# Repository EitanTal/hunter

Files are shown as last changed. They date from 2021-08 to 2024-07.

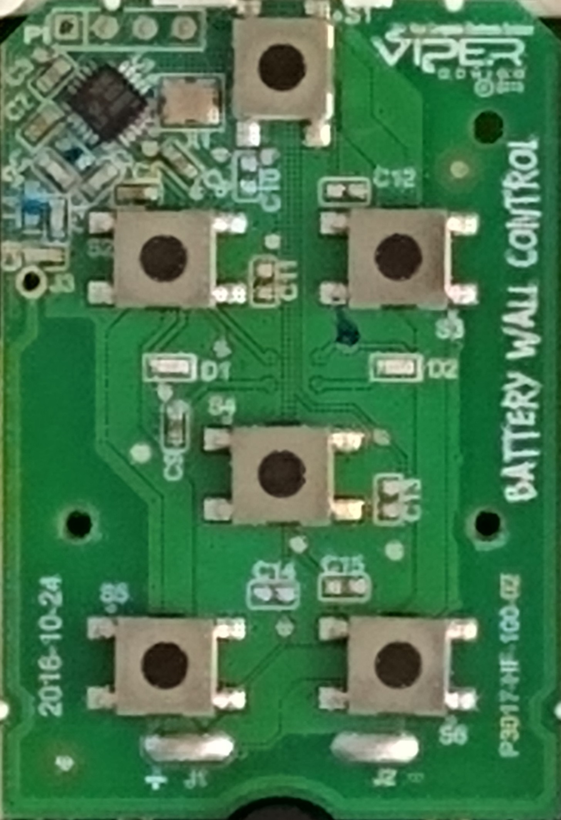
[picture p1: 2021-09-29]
PCB/ffs.jpg

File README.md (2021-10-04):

# Intro

This is a recreation of an Old-school Hunter fan remote

## Digital signals

Every packet is as follows:

   [`address`][`opcode`]

address is 5 bits long, opcode is 8 bits long. Address used = 0b01111

### Packets & Opcodes

* light:    0x0F (01111) 0x1 (00000001)
* fan off:  0x0F (01111) 0x2 (00000010)
* fan rev:                   (00000100)
* fan 3:                     (00001000)
* fan 2:                     (00010000)
* fan 1:    0x0F             (00100000)

## Pulse layout

short pulse: (0)

      _
    __

long pulse: (1)

     __
    _

## Pulse timing

length of each character: 328.4us (0.3284ms)

every 1 bit = 8us.
41 bits = one unit.
~16 bytes per triplet.

This equals a baudrate of 3045

The bit burst must repeat 16 times.
There must be exactly 10ms gap between each bit burst.

## Radio notes

### Carrier

The chosen carrier is 302MHz. The original remote is inconsistent on its carrier wave, ranging from 300 to 305.

### Modulation

On-off-keying modulation is used. (AM)

### RF backend

This implementation utilizes TI CC1101 as the RF backend. The original hunter remote presumably used a ferrite core antenna. More details are available in eariler revisions.

As an antenna, a 30cm wire is used.

For power, 0db is currently used

## Breadboard notes

CC1101 operates on 3v3 max. Resistor divider used on Arduino -> CC1101

Relevant pins on the pinheader of the eval board of CC1101:
| Color | Pin |  | Pin  | Color |
|---|---|--|---|---|
|  Brown  | VCC |  | VCC | Red |
|  Orange | SCK |  | MOSI | Yellow  |
|  Green  | GDO2  |  | MISO | Blue |
|  Purple | GDO0  |  | CSN | Grey |
|  White  | GND |  | GND | Black |

The pins as they connect to my breadboard:
| Color | Pin |  | Pin  | Color |
|---|---|--|---|---|
| (Black) |GND |  | VCC | (Red) |
| (Blue)  |MISO |  | MOSI |(Yellow) |
| (Orange)|SCK |  | CSN |  (Grey) |
| | |  | GDO0 |(Purple) |

Relevant pins on the arduino:
|Number|Function|Comment |
|---|---|---|
|10 | SS | (Active low) |
|11 | MOSI | |
|12 | MISO | |
|13 | SCLK | |
|2 | GDO0 | (Interrupt line 0, PD2) |

Breadboard jumper cables:
arduino-breadboard line
2-21
7-19
10-15
11-13
12-17
13-9

## STM8 pins

|Arduino|Function|207K (Eval board) |101F (Target)  |
|---|---|---|---|
|10 | SS |PE5 (D10) |PB4 |
|11 | MOSI |PC6 (D11) |PB6 |
|12 | MISO |PC7 (D12) |PB7 |
|13 | SCLK |PC5 (D13) |PB5 |
|2 | GDO0 |PD0 (D2) |PC0 |

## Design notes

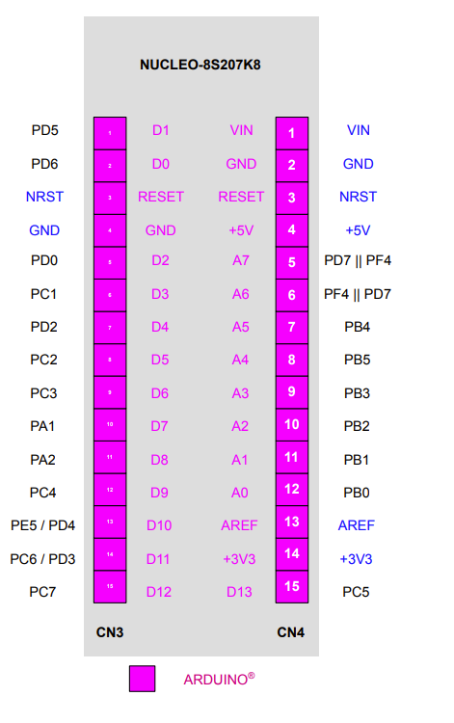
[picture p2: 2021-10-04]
docs/Nucleo_Pinout.PNG

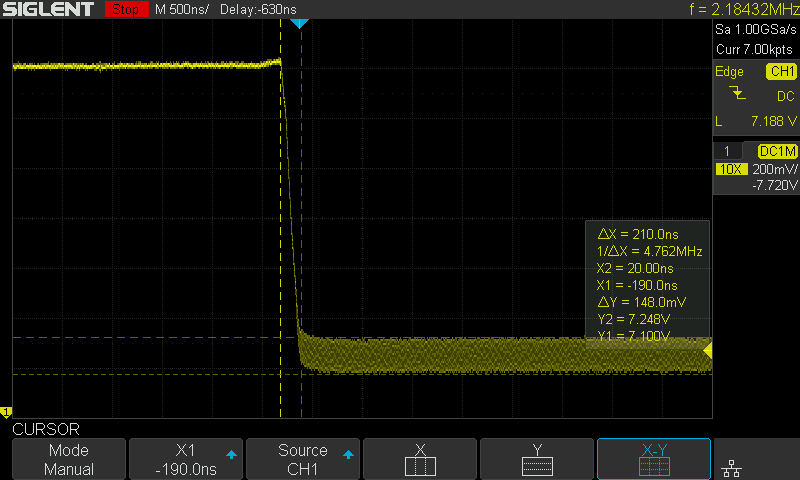
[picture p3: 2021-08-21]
waveforms/point1_fall_2.png

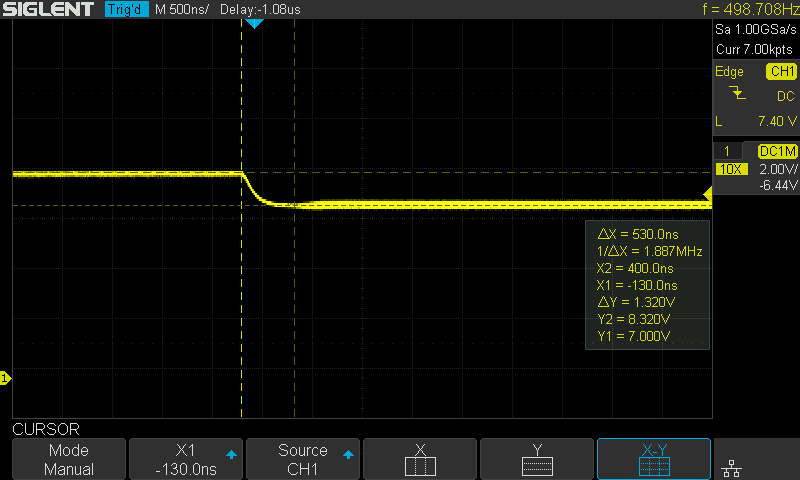
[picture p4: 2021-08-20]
waveforms/hunter_collector_fall.png

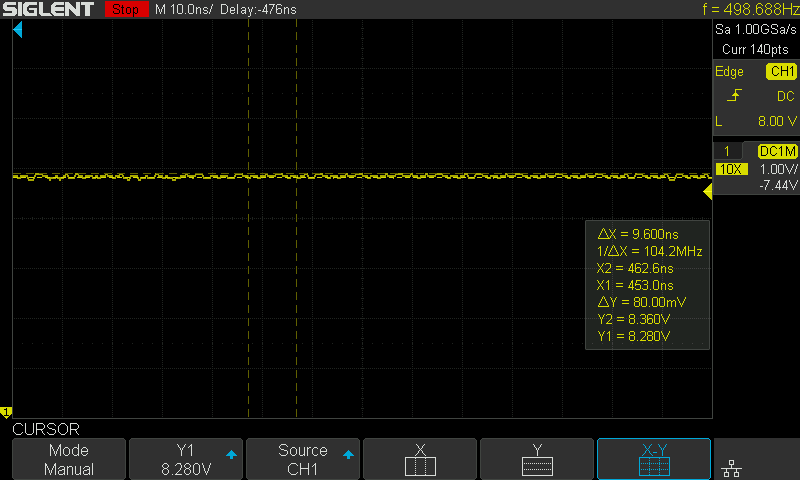
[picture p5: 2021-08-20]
waveforms/hunter_collector_h.png

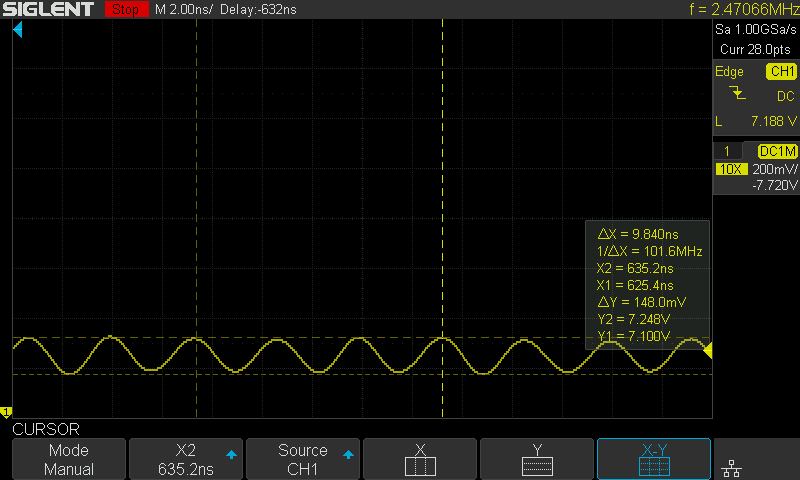
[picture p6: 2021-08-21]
waveforms/point1_l.png

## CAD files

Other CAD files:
hunter.stp

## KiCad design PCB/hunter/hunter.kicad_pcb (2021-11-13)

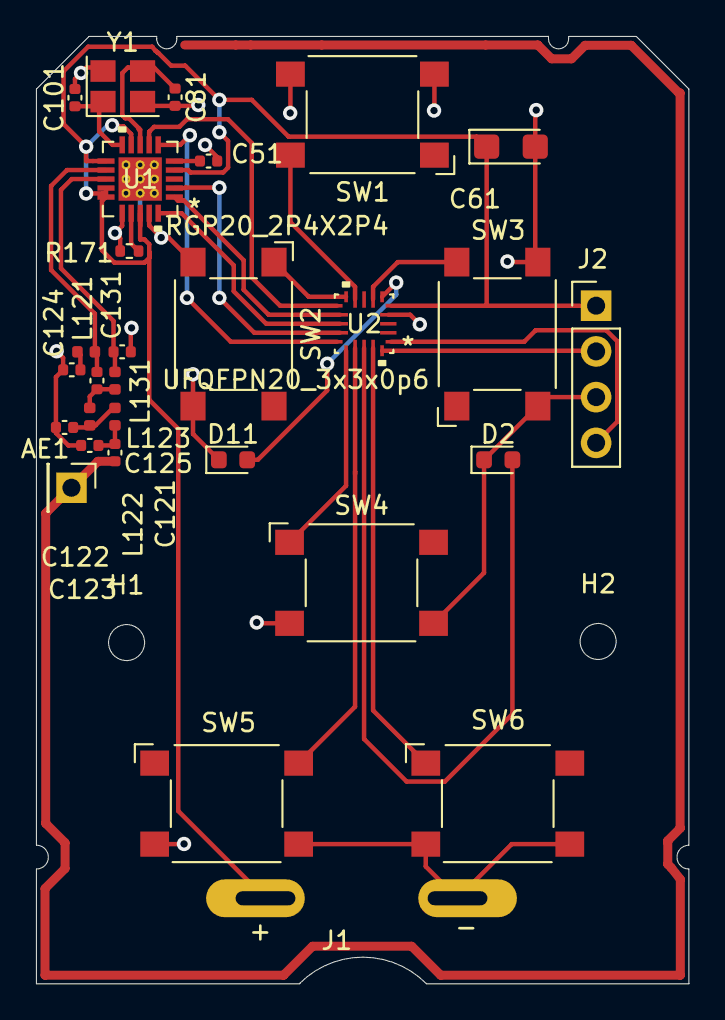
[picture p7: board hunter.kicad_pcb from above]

Board: 2 copper layers, 36.2 x 52.6 mm, 31 parts (0 on the bottom side), 28 nets.

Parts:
AE1: Antenna; PinHeader_1x01_P2.54mm_Vertical
C51: 100nF; C_0402_1005Metric
C61: 10uF; CP_EIA-3216-18_Kemet-A
C81, C101: 27pF; C_0402_1005Metric
C121, C123, C131: 6.8pF; C_0402_1005Metric
C122: 12pF; C_0402_1005Metric
C124, C125: 220pF; C_0402_1005Metric
D2: LED2; LED_0603_1608Metric
D11: LED1; LED_0603_1608Metric
H1, H2: MountingHole; MountingHole_2mm
J1: Battery; MyBatteryConnector
J2: JTAG; PinHeader_1x04_P2.54mm_Vertical
L121, L123, L131: 33nH; L_0402_1005Metric
L122: 18nH; L_0402_1005Metric
R171: 56k; R_0402_1005Metric
SW1: SW_Light; SW_SPST_Omron_B3FS-100xP
SW2: SW_LightUp; SW_SPST_Omron_B3FS-100xP
SW3: SW_LightDown; SW_SPST_Omron_B3FS-100xP
SW4: SW_Fan; SW_SPST_Omron_B3FS-100xP
SW5: SW_FanUp; SW_SPST_Omron_B3FS-100xP
SW6: SW_FanDown; SW_SPST_Omron_B3FS-100xP
U1: RGP20_2P4X2P4; CC1101RGPR
U2: UFQFPN20_3x3x0p6; STM8L101F3U6TR
Y1: 25MHz; Crystal_SMD_3225-4Pin_3.2x2.5mm

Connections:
+3V0: C61.1, J1.1, J2.1, U1.4, U1.9, U1.11, U1.14, U1.15, U1.18, U2.5
GND: C51.2, C61.2, C81.1, C101.2, C122.2, C123.2, C124.2, C131.1, D2.1, D11.1, J1.2, J2.3, R171.1, SW1.3, SW1.4, SW2.3, SW2.4, SW3.3, SW3.4, SW4.3, SW4.4, SW5.3, SW5.4, SW6.3, SW6.4, U1.16, U1.19, U1.21, U1.V, U2.4, Y1.2, Y1.4
unnamed: AE1.1, C125.1
unnamed: C51.1, U1.5
unnamed: C81.2, U1.8, Y1.3
unnamed: C101.1, U1.10, Y1.1
unnamed: C121.1, L121.1, U1.12
unnamed: C121.2, L122.1, L131.2
unnamed: C122.1, L122.2, L123.1
unnamed: C123.1, C125.2, L123.2
unnamed: C124.1, L121.2
unnamed: C131.2, L131.1, U1.13
unnamed: D2.2, U2.18
unnamed: D11.2, U2.6
unnamed: J2.2, U2.20
unnamed: J2.4, U2.1
unnamed: R171.2, U1.17
unnamed: SW1.2, U2.9
unnamed: SW2.1, U2.10
unnamed: SW3.2, U2.7
unnamed: SW4.1, U2.16
unnamed: SW5.2, U2.17
unnamed: SW6.1, U2.19
unnamed: U1.1, U2.12
unnamed: U1.2, U2.14
unnamed: U1.6, U2.15
unnamed: U1.7, U2.11
unnamed: U1.20, U2.13

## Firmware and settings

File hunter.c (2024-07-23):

#include "CC1101.h"
#include "hunter_data.h"
#include "main.h"
#include "io.h"
#include "time.h"
#include "stm8l10x_clk.h"
#include "stm8l10x_exti.h"

enum
{
  BUTTON_LIGHT = PIN_Z0,
  BUTTON_LIGHT_UP = PIN_Z1,
  BUTTON_LIGHT_DOWN = PIN_A0,
  BUTTON_FAN = 3,
  BUTTON_FAN_UP = 5,
  BUTTON_FAN_DOWN = 9
};

enum
{
	MY_LED_11 = 2, // Arduino D2 equivalent
	MY_LED_2  = 6  // Arduino D6 equivalent
};

enum
{
  COMMAND_ERROR,
  COMMAND_OK
};

#define PULL_UP_RESISTOR_PRESENT

////////////////////////////////////////////////////////


static void WFI(void)
{
  AWU_IdleModeEnable();
	//__asm("WFI");
  __asm("HALT");
}

static void ENABLE_INTERRUPTS(void)
{
	__asm("RIM");
}

void setup(void)
{
  CLK_PeripheralClockConfig(CLK_Peripheral_SPI, ENABLE);
  
	pinMode(MY_LED_11, OUTPUT);
	pinMode(MY_LED_2, OUTPUT);

  pinMode(BUTTON_LIGHT, INPUT_PULLUP);
  pinMode(BUTTON_LIGHT_UP, INPUT_PULLUP);
  pinMode(BUTTON_LIGHT_DOWN, INPUT_PULLUP);
  pinMode(BUTTON_FAN, INPUT_PULLUP);
  pinMode(BUTTON_FAN_UP, INPUT_PULLUP);
  pinMode(BUTTON_FAN_DOWN, INPUT_PULLUP);

  EXTI_SetPortSensitivity(EXTI_Port_B, EXTI_Trigger_Falling); // B2
  EXTI_SetPinSensitivity(EXTI_Pin_0, EXTI_Trigger_Falling);   // B0
  EXTI_SetPinSensitivity(EXTI_Pin_1, EXTI_Trigger_Falling);   // C1
  EXTI_SetPinSensitivity(EXTI_Pin_2, EXTI_Trigger_Falling);   // C2
  EXTI_SetPinSensitivity(EXTI_Pin_3, EXTI_Trigger_Falling);   // B3
  EXTI_SetPinSensitivity(EXTI_Pin_4, EXTI_Trigger_Falling);   // C4

  //cc1101_init();
  AWU_Init(AWU_Timebase_1ms);
  
  delay(1000);

  ENABLE_INTERRUPTS();
}

void send_action(int action, int ok)
{
  uint8_t *tx_buf;
  int i;
	int j;
  //int loop_count = (action == DATA_LIGHT) ? 5 : 16; // Light button requires less repetitions, or else it is counted as a double click.
  int loop_count = 5;
  int loop_count2 = (action == DATA_LIGHT) ? 1 : 3; // Light button requires less repetitions, or else it is counted as a double click.
  hunter_data_clear();
  hunter_data_add_bits(0x0F, 5);
  hunter_data_add_bits(action, 8);
  tx_buf = hunter_data_get_buffer();
	
  for (j = 0; j < loop_count2; j++)
  {
	cc1101_init();

  for (i = 0; i < loop_count; i++)
  {
    if (ok == COMMAND_OK)
    {
      digitalWrite(MY_LED_11, ((i%2) ? HIGH : LOW));
      digitalWrite(MY_LED_2, ((i%2) ? HIGH : LOW));
    }
    else
    {
      digitalWrite(MY_LED_11, (((i/4)%2) ? HIGH : LOW));
      digitalWrite(MY_LED_2, (((i/4)%2) ? LOW : HIGH));
    }
    cc1101_sendData(tx_buf, SIZEOF_HUNTER_DATA_BUFFER);
    delay(10);
  }
  }
	
	cc1101_off();
}

int speed2action(int8_t new_speed)
{
  switch (new_speed)
  {
    case 1:    return DATA_FAN_3;
    case 2:    return DATA_FAN_2;
    case 3:    return DATA_FAN_1;
  }
  return DATA_FAN_OFF;
}

void loop(void)
{
  static int8_t current_fan_speed = 0;
  static int8_t saved_fan_speed = 3; // Default to highest speed.

  digitalWrite(MY_LED_11, LOW);
  digitalWrite(MY_LED_2, LOW);
  delay(100);
  cc1101_off(); // turn off again before going to sleep, just in case
	WFI();

  if (digitalRead(BUTTON_LIGHT) == LOW)
  {
    send_action(DATA_LIGHT, COMMAND_OK);
  }
#if 0 // No support for light-up / light-down
  if (digitalRead(BUTTON_LIGHT_UP) == LOW) action = DATA_FAN_OFF;
  if (digitalRead(BUTTON_LIGHT_DOWN) == LOW) action = DATA_FAN_REVERSE;
#endif

#ifdef PULL_UP_RESISTOR_PRESENT
  if (digitalRead(BUTTON_FAN) == LOW)
  {
    if (current_fan_speed == 0) 
    {
      // If the fan is not running, recall the saved fan speed.
      current_fan_speed = saved_fan_speed;
    }
    else
    {
      // If the fan is running, store its current speed and stop the fan.
      saved_fan_speed = current_fan_speed;
      current_fan_speed = 0;
    }
    send_action(speed2action(current_fan_speed), COMMAND_OK);
  }
#else
#warning "Special build: No pull-up resistor"
#endif
  if ((digitalRead(BUTTON_FAN_UP) == LOW) && (digitalRead(BUTTON_FAN_DOWN) == LOW))
  {
    send_action(DATA_FAN_REVERSE, COMMAND_OK);
  }
  else
  {
    if (digitalRead(BUTTON_FAN_UP) == LOW)
    {
      current_fan_speed++;
      if (current_fan_speed > 3) 
      {
        current_fan_speed = 3;
        send_action(speed2action(current_fan_speed), COMMAND_ERROR);
      }
      else
      {
        send_action(speed2action(current_fan_speed), COMMAND_OK);
      }
    }
    if (digitalRead(BUTTON_FAN_DOWN) == LOW)
    {
      current_fan_speed--;
      if (current_fan_speed < 0)
      {
        current_fan_speed = 0;
        send_action(speed2action(current_fan_speed), COMMAND_ERROR);
      }
      else
      {
        send_action(speed2action(current_fan_speed), COMMAND_OK);
      }
    } 
  }
}

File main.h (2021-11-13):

#pragma once

enum // ! Arduino
{
    PINB,
    PIND,
    PORTB,
    PIN_A0 = 14,
    PIN_A1 = 15,
    PIN_Z0 = 16,
    PIN_Z1 = 17,
    PIN_Z2 = 18,
    PIN_Z3 = 19,
    PIN_Z4 = 20,
    PIN_Z5 = 21,
    PIN_Z6 = 22
};

#if 0
#define SPI_SS   10     // PB2 = SPI_SS
#define SPI_MOSI 11     // PB3 = MOSI
#define SPI_MISO 12     // PB4 = MISO
#define SPI_SCK  13     // PB5 = SCK
#define GDO0	 2        // PD2 = INT0

#define PORT_SPI_MISO  PINB
#define BIT_SPI_MISO  4

#define PORT_SPI_SS  PORTB
#define BIT_SPI_SS   2

#define PORT_GDO0  PIND
#define BIT_GDO0  2
#else
#define SPI_SS   PIN_Z2     // PB4 = SPI_SS
#define SPI_MOSI PIN_Z4     // PB6 = MOSI
#define SPI_MISO PIN_Z5     // PB7 = MISO
#define SPI_SCK  PIN_Z3     // PB5 = SCK
#define GDO0	 PIN_Z6     // PC0 = INT0
#endif

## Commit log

2021-08-07 added circuit diagram + links
2021-09-26 Stm8 (#3)
    [hunter.stp]
2021-09-29 PCB initial commit (#4)
    * PCB outline
    * first button, correction to the board cut
    * formfactor pictures
    * ignorelist
    * parts lib: cc1101, stm8l101, MyBatteryConnector
    * button lib
    * CPU: schematics
    * CC1101 schematics, balun and anetanna
    * Coupling capacitor, assign refences from datasheet
    * CC1101: values and footprints
    * rearrangement
    * Schematics Complete, all foootprint assignments done
    [hunter.kicad_pcb, hunter.sch]
2021-10-04 Full code port (into Nucleo) (#5)
    [hunter.stp]
2021-11-13 Migrate to real hardware (#6)
    [hunter.stp]
2021-11-13 Fully functional PCB (Phase 2) (#8)
    [hunter.kicad_pcb, hunter.sch]
2021-11-14 fan button toggles fan on and off. (instead of just off)
2024-07-23 current consumption fix attempt
    [cc1101.c, hunter.c]

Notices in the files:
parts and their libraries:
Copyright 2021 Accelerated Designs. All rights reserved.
